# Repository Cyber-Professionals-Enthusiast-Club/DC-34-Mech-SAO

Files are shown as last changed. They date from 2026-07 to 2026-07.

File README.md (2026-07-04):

# About
This repository contains design files for the CPEC SAO pluggin modules for the 
CPEC DC 34 badge. 

# Structure 
- Artis_art/ directory for art files (.svg vector graphics)
- DC34-Mech-SAO/ directory for circuit board design files (kicad 6 project)
- DC34-Mech-SAO-Firmware/ directory for the arduino file to load onto the SAO
- libraries/ directory for kicad symbols and footprint files 

## Running
To view schematics, please run KiCad 6.0.11 or later. Change directory into 
DC-34-Mech-SAO and run
```
kicad DC-34-Mech-SAO.kicad_pro
```

Please note: please run kicad from the same directory as the .kicad_pro file 
is stored because the fp-lib-table and sym-lib-table use relative paths 
so that this project is portable between computers.

# Development Rules
- No spaces in file names or directories because this causes some tools to not 
beable to load the files
- Do not check in binary files because this bloats the repo, instead generate 
them with scripts from ASCII files and add the binary extension to the 
.gitignore file

# Associated Repos
Board firmware is developed in this repo: 
[ttps://github.com/eggsactly/DcC4-Mech-SAO-Plugin-Demo](https://github.com/eggsactly/DcC4-Mech-SAO-Plugin-Demo)

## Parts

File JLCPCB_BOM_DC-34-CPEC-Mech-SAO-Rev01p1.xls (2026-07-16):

Comment | Designator | Footprint | JLCPCB Part#(optional)
10uF | C1 | 0402 | C408132
0.1uF | C2 | 0201 | C85923
2.54-2*3P立贴针 | J1 | SMD,P=2.54mm,Surface Mount,Right Angle | C192301
2KΩ | R1 | 0402 | C137887
10KΩ | R2-13 | 0402 | C6111655
Attiny-816 | U1 | VQFN20 | C152217
LTST-C190KGKT | D1 | 0603 | C125094
LTST-C190KRKT | D2 | 0603 | C94869
DNP (Do not Populate) | J2 | DNP (Do not Populate) | DNP (Do not Populate)

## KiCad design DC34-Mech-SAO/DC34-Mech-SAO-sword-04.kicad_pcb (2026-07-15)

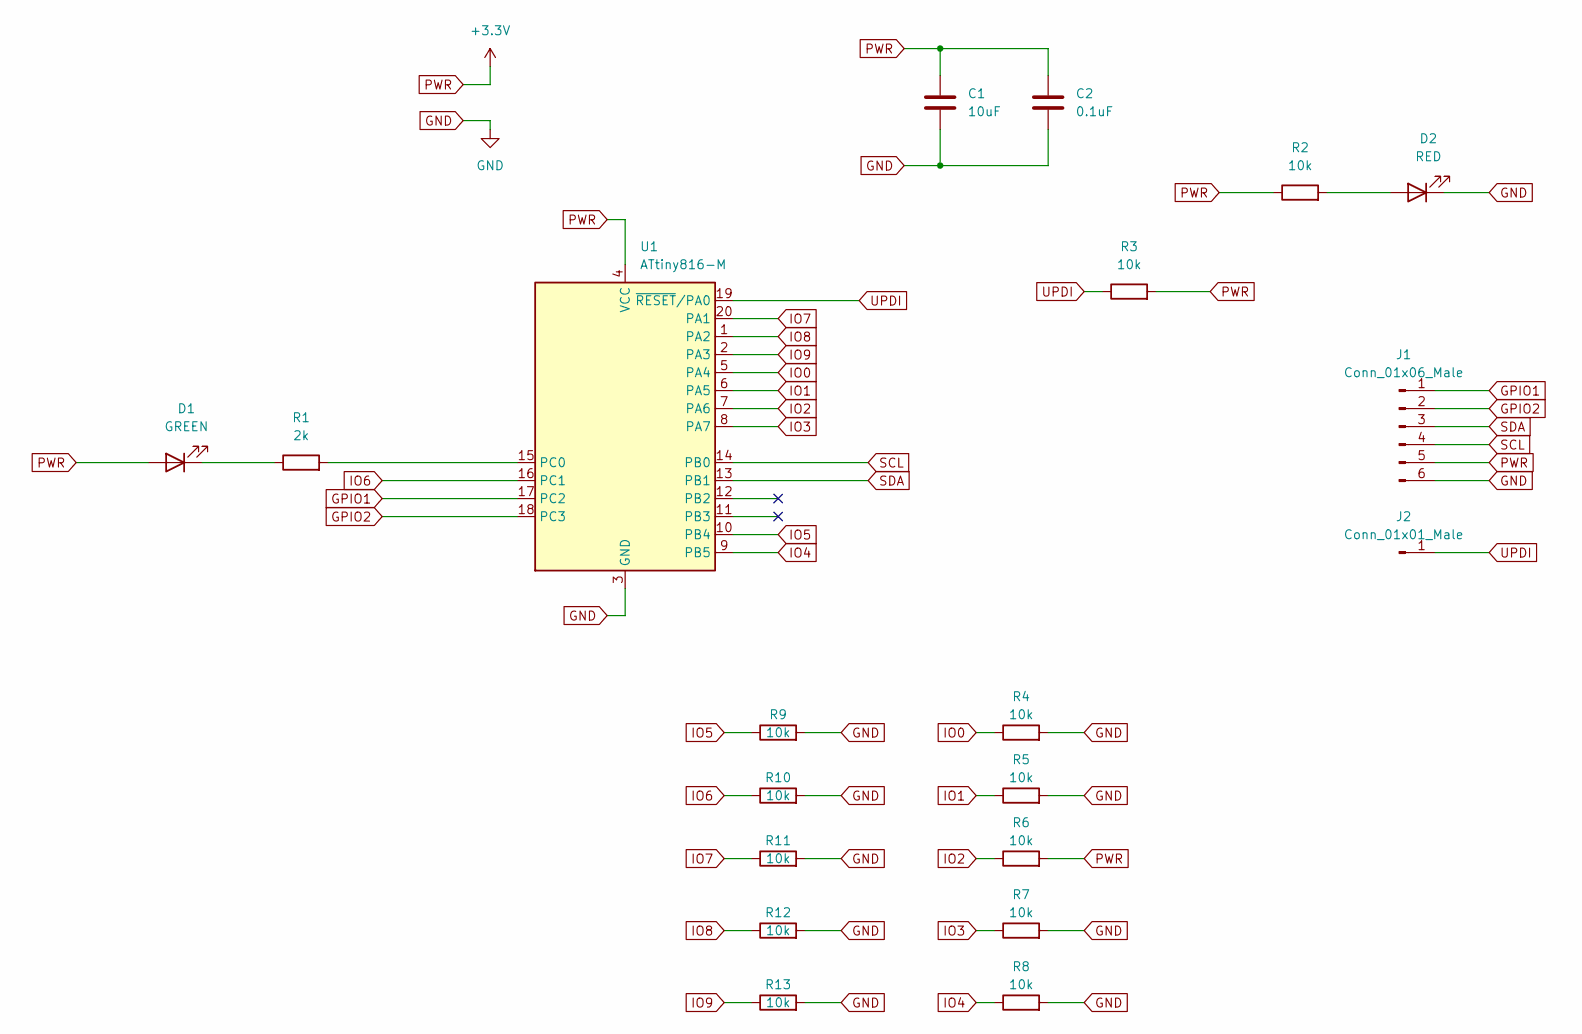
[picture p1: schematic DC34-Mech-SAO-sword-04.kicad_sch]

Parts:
C1: 10uF; C_0402_1005Metric
C2: 0.1uF; C_0201_0603Metric
D1: GREEN; LED_0603_1608Metric_Pad1.05x0.95mm_HandSolder
D2: RED; LED_0603_1608Metric_Pad1.05x0.95mm_HandSolder
J1: Conn_01x06_Male; PinSocket_2x03_P2.54mm_Vertical_SMD
J2: Conn_01x01_Male; Aligator_TIP
R1: 2k; R_0402_1005Metric
R2, R3, R4, R5, R6, R7, R8, R9, R10, R11, R12, R13: 10k; R_0402_1005Metric
U1: ATtiny816-M; VQFN20_3X3_MCH

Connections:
GND: C1.2, C2.2, D2.1 (K), J1.6, R4.2, R5.2, R7.2, R8.2, R9.2, R10.2, R11.2, R12.2, R13.2, U1.3 (GND), U1.21 (GND)
GPIO1: J1.1, U1.17 (PC2)
GPIO2: J1.2, U1.18 (PC3)
IO0: R4.1, U1.5 (PA4)
IO1: R5.1, U1.6 (PA5)
IO2: R6.1, U1.7 (PA6)
IO3: R7.1, U1.8 (PA7)
IO4: R8.1, U1.9 (PB5)
IO5: R9.1, U1.10 (PB4)
IO6: R10.1, U1.16 (PC1)
IO7: R11.1, U1.20 (PA1)
IO8: R12.1, U1.1 (PA2)
IO9: R13.1, U1.2 (PA3)
unnamed: D1.1 (K), R1.1
unnamed: D2.2 (A), R2.2
unnamed: R1.2, U1.15 (PC0)
PWR: C1.1, C2.1, D1.2 (A), J1.5, R2.1, R3.2, R6.2, U1.4 (VCC)
SCL: J1.4, U1.14 (PB0)
SDA: J1.3, U1.13 (PB1)
UPDI: J2.1, R3.1, U1.19 (~RESET/PA0)

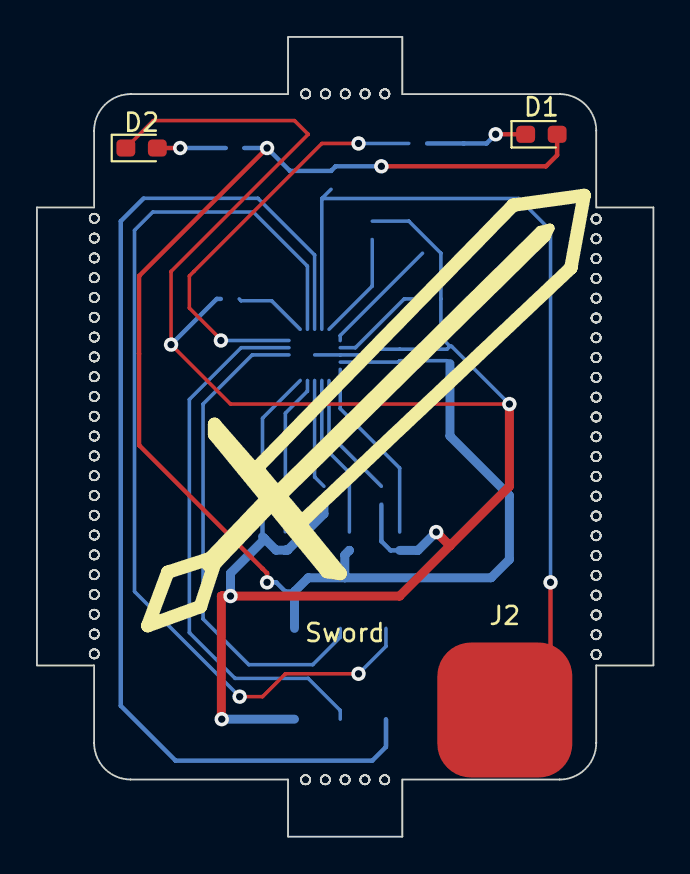
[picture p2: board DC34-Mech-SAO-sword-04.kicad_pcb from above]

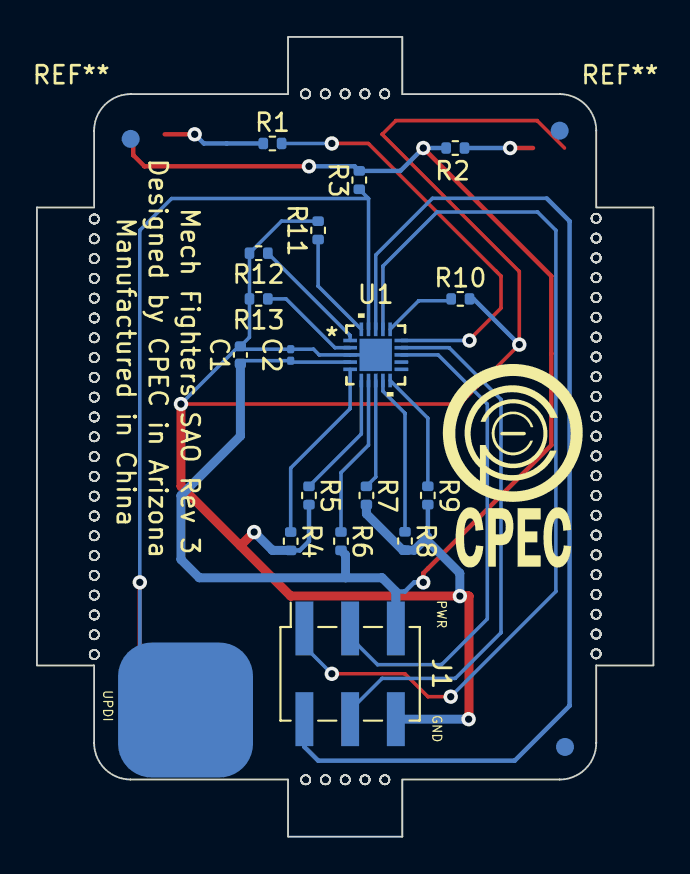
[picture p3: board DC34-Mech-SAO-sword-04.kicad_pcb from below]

Board: 2 copper layers, 34.2 x 44.4 mm, 20 parts (17 on the bottom side), 20 nets.

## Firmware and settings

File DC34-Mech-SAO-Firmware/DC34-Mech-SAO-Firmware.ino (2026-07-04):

// DC34-Mech-SAO-Firmware is the program for the small mech weapon boards.
// All boards take the exact same program. 
// Boards are configured by different resistors on the individual boards.
// There is no need to change anything in the program between boards.
// They're configured at the hardware level. 
//
// This program is based on the example_pid5681 Arduino sketch for the Adafruit ATtiny 816
//
/*
 * Arduino IDE setup
 * Programming requires a UPDI programmer ($7 in 2026)
 * https://www.digikey.com/en/products/detail/adafruit-industries-llc/5879/22596413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
 * 
 * File > Preferences > Additional Boards Manager URLs: paste the following URL
 * http://drazzy.com/package_drazzy.com_index.json
 * 
 * Tools > Board > Boards Manager...
 * Search for megaTinyCore
 * Install megaTinyore by Spence Konde
 * 
 * Tools > Board > megaTinyCore > ATtiny 3226/3216/1616/1606/816/806/416/406 w/Optiboot
 * Tools > Chip: > ATtiny816
 * Tools > Clock: > 10 MHz internal
 * Tools > Programmer > SerialUPDI - SLOW: 57600 baud 
 * 
 * On the UPDI friend, make sure the switch is flipped to 3V
 * 
 * Attach the UPDI Friend programmer between your computer and connector J2 on the circuit, connecting
 * GND -> GND
 * PWR -> PWR
 * UPDI -> UPDI
 * 
 * Sketch > Upload Using Programmer 
 * You will see the red LED flicker on the UPDI friend.
 * If this does not work, you may need to go to
 * Tools > Port
 * and select a serial port.
 */

/*
 * Mapping of GPIO pins to attiny816 pins 
 * GPIO - ATTINY816 Pin
 * 0    - 5
 * 1    - 6
 * 2    - 7
 * 3    - 8
 * 4    - 9
 * 5    - 10
 * 6    - 11
 * 7    - 12
 * 8    - 13
 * 9    - 14
 * 10   - 15
 * 11   - 16
 * 12   - 17
 * 13   - 18
 */
 
 #define PRODUCT_CODE            5681
#define CONFIG_I2C_PERIPH_ADDR  0x49
//#define CONFIG_UART_DEBUG         1

#define CONFIG_INTERRUPT_PIN        6
//#define USE_PINCHANGE_INTERRUPT   1

// Can have up to 3 addresses
#define CONFIG_ADDR_0_PIN          12
#define CONFIG_ADDR_1_PIN          13

#define CONFIG_ADC                 1
#define CONFIG_PWM                 1
#define CONFIG_NEOPIXEL            1
#define CONFIG_NEOPIXEL_BUF_MAX   (60*3) // 60 pixels == 180 bytes

#include "Adafruit_seesawPeripheral.h"

void setup() {
#if CONFIG_UART_DEBUG
  Serial.begin(115200);
  delay(500);
#endif
  delay(1);
  Adafruit_seesawPeripheral_begin();
}


void loop() {
  Adafruit_seesawPeripheral_run();
}

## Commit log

2026-04-14 Created board design.
    [DC34-Mech-SAO.kicad_pcb, DC34-Mech-SAO.kicad_sch]
2026-04-20 Using ATTiny 816.
    [DC34-Mech-SAO.kicad_pcb, DC34-Mech-SAO.kicad_sch]
2026-05-01 Addressed clearence issue.
    [DC34-Mech-SAO.kicad_pcb]
2026-05-01 Added silkscreen.
    [DC34-Mech-SAO.kicad_pcb]
2026-07-04 Added board firmware
2026-07-15 Updates to project over last few days.
    [DC34-Mech-SAO.kicad_pcb, DC34-Mech-SAO.kicad_sch]
2026-07-15 Panelized Design
    Put all 5 designs on a panel.
    [DC34-Mech-SAO-fist-03.kicad_pcb, DC34-Mech-SAO-fist-03.kicad_sch, DC34-Mech-SAO-gatling-01.kicad_pcb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]
2026-07-15 Added JLCPCB BOM
    [JLCPCB_BOM_DC-34-CPEC-Mech-SAO-Rev01p1.xls]
2026-07-15 Attempt to pass DRC.
    [JLCPCB_BOM_DC-34-CPEC-Mech-SAO-Rev01p1.xls]
2026-07-16 Update DC34-Mech-SAO-panel.kicad_pcb
    Got board outline completely enclosed.
2026-07-16 More Small Updates
    Added small updates to board to get the gbr files to output without errors.
2026-07-16 Updated BOM to match JLCPCB template.
    [JLCPCB_BOM_DC-34-CPEC-Mech-SAO-Rev01p1.xls]
2026-07-16 Created placement file for JLCPCB
    [DC-34-CPEC-Mech-SAO-Rev01p1-CPL_JLCSMT.xlsx]
2026-07-16 Removed J2 from position file.
    [DC-34-CPEC-Mech-SAO-Rev01p1-CPL_JLCSMT.xlsx]
2026-07-16 Updates to BOM.
    [JLCPCB_BOM_DC-34-CPEC-Mech-SAO-Rev01p1.xls]
2026-07-16 Create DC34-Mech-SAO-fist-03.kicad_prl
    Updates for JLCPCB gerber format.
2026-07-16 Update DC34-Mech-SAO-panel.kicad_pcb
    Update output format for JLCPCB.
2026-07-16 Update DC34-Mech-SAO-panel.kicad_pcb
    Another fix to the bad outline.
2026-07-16 Attempt to align placement file with JLCPCB coordinate system.
    [DC-34-CPEC-Mech-SAO-Rev01p1-CPL_JLCSMT.xlsx]
